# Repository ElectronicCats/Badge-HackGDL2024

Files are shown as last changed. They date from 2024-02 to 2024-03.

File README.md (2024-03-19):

# Badge Hack GDL 2024
Inspirado en la piñata mas famosa del Guadalajara este es el badge electronico de [HackGDL](https://hackgdl.net/)

## Características

- Microcontrolador Puya PY32F002AA15M6TU
- Baterias CR2030
- 4 LEDs SMD

# Firmware
- Para hacer cambios en el firmware revisar el [README](https://github.com/ElectronicCats/Badge-HackGDL2024/tree/main/firmware#readme)

## License
<a>
  
</a>

Diseñado por Electronic Cats para HackGDL

Electronic Cats invests time and resources in providing this open-source design. Please support Electronic Cats and open-source hardware by purchasing products from Electronic Cats!

Hardware released under

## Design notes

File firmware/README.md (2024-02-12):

## Characteristics

* Microcontroller Puya PY32F002A    
  * PY32F002Ax5(20KB Flash/3KB RAM) SPI, USART, I2C, ADC.

## License
<a>
  
</a>

Designed by Electronic Cats for HackGDL

Electronic Cats invests time and resources in providing this open-source design. Please support Electronic Cats and open-source hardware by purchasing products from Electronic Cats!

Hardware released under ...

# PY32F0 SDK reference for Windows

[How to install the SDK for windows](https://github.com/ElectronicCats/puya-projects)

* Puya PY32F0 seriees template project for GNU Arm Embedded Toolchain
* Supported programmers: J-Link
* Supported IDE: VSCode

# File Structure

```
├── Build                       # Build results
├── Docs                        # Datesheets and User Manuals
├── Examples
│   ├── FreeRTOS                # FreeRTOS examples
│   ├── HAL                     # HAL library examples
│   └── LL                      # LL(Low Layer) library examples
├── Libraries
│   ├── BSP                     # SysTick delay and printf for debug
│   ├── BSP_LL                  # SysTick delay and printf for debug
│   ├── CMSIS
│   ├── FreeRTOS                # FreeRTOS library
│   ├── LDScripts               # LD files
│   ├── PY32F0xx_HAL_Driver     # MCU peripheral driver
│   └── PY32F0xx_LL_Driver      # MCU low layer peripheral driver
├── Makefile                    # Make config
├── Misc
│   ├── Flash
│   │   ├── JLinkDevices        # JLink flash loaders
│   │   └── Sources             # Flash algorithm source code
│   ├── Puya.PY32F0xx_DFP.x.pack # DFP pack file for PyOCD
│   └── SVD                     # SVD files
├── README.md
├── rules.mk                    # Pre-defined rules include in Makefile 
└── User                        # User application code
```

# Requirements

* Programmer
  * J-Link: J-Link OB programmer: https://linhkienthuduc.com/jlink-ob-072-mach-nap-cho-arm-cortex-m
* SEGGER J-Link Software and Documentation pack [https://www.segger.com/downloads/jlink/](https://www.segger.com/downloads/jlink/)
* GNU Arm Embedded Toolchain
* Make 

# Try Other Examples

[Forked Repository](https://github.com/IOsetting/py32f0-template)
More examples can be found in *Examples* folder of the forked repository, copy and replace the files under *User* folder of this repository to try different examples.

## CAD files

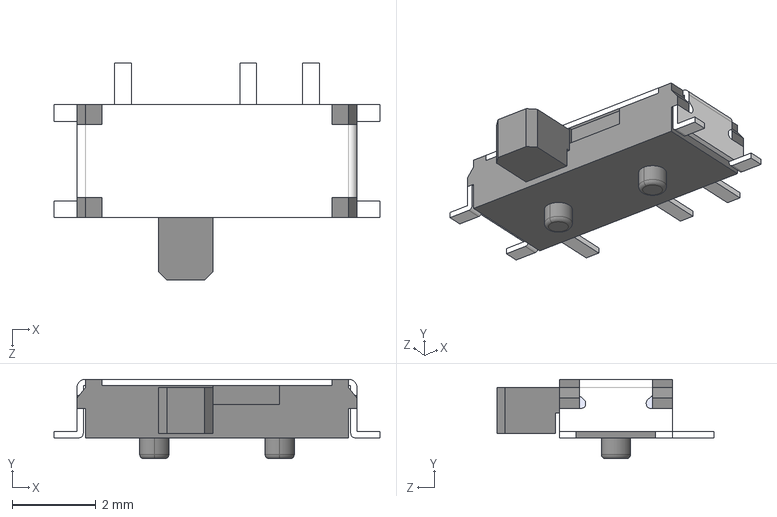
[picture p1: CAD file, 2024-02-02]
hardware/Footprints/3D/MSK12C02.stp
7.80 x 1.90 x 5.20 mm

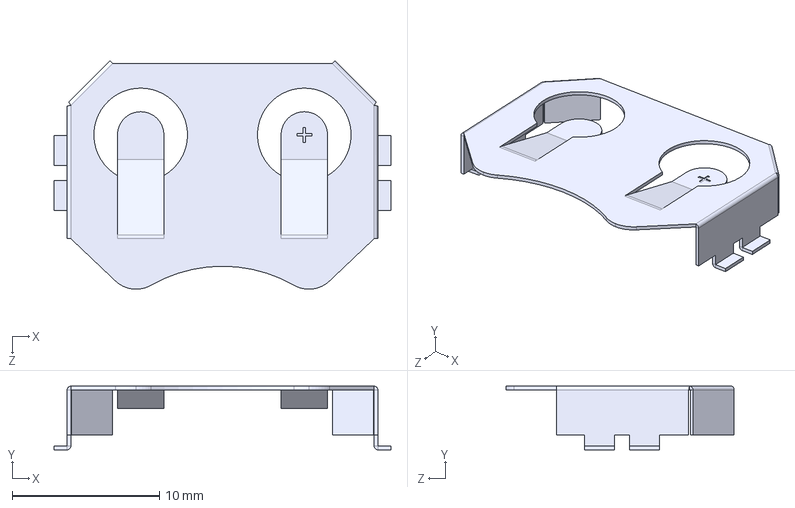
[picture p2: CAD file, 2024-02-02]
hardware/Footprints/3D/BAT-HLD-001--3DModel-STEP-56544.STEP
22.9 x 4.32 x 15.5 mm

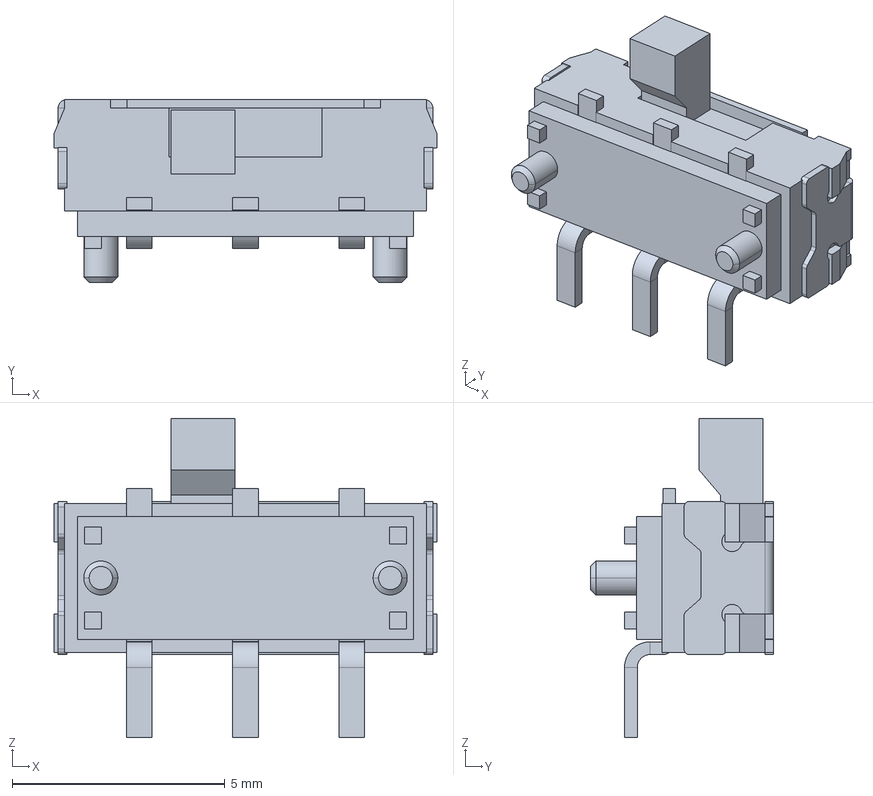
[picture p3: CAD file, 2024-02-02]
hardware/Footprints/3D/JS102011SAQN--3DModel-Eagle-1.STEP
9.00 x 4.30 x 7.50 mm

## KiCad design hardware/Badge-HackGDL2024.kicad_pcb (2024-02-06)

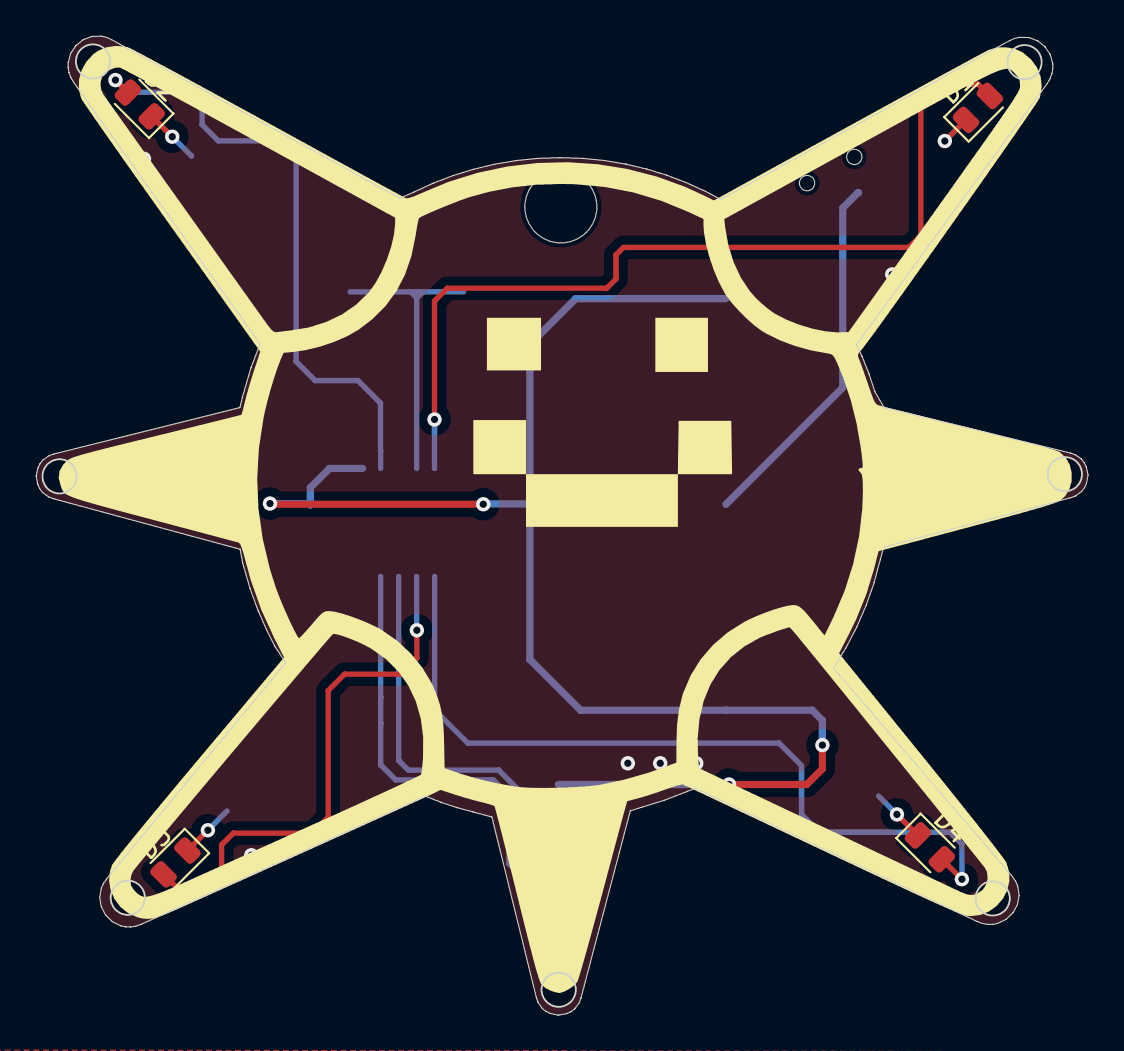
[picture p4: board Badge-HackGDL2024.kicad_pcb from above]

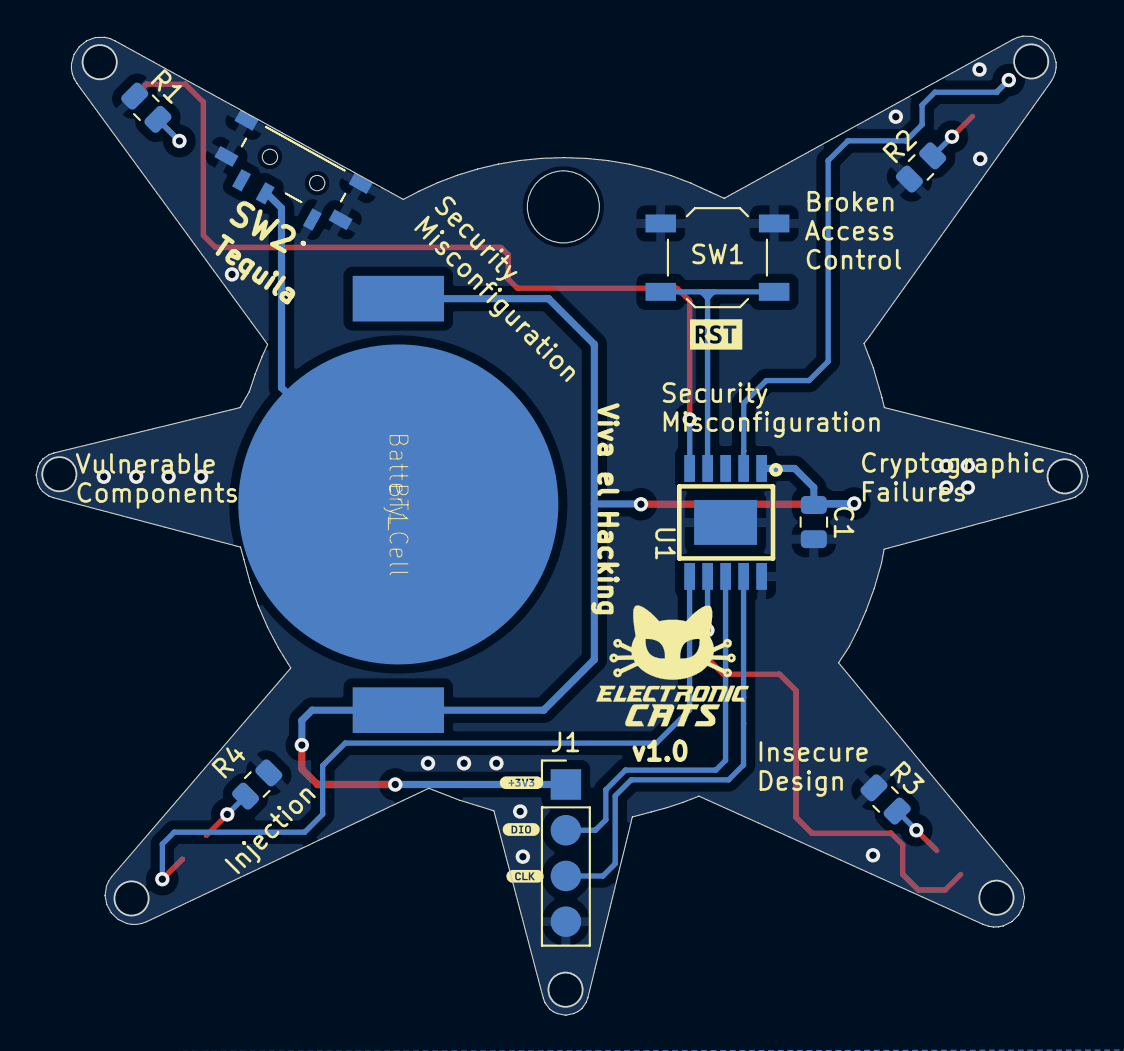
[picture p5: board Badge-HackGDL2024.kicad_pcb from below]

Board: 2 copper layers, 58.4 x 54.4 mm, 18 parts (14 on the bottom side), 14 nets.

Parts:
BT1: Battery_Cell; BAT-HLD-001
C1: 0.1uF; C_0805_2012Metric
D1: Blue; LED_0805_2012Metric
D2: Green; LED_0805_2012Metric
D3: Red; LED_0805_2012Metric
D4: Yellow; LED_0805_2012Metric
J1: SWD; PinHeader_1x04_P2.54mm_Vertical
R1, R2, R3, R4: 330R; R_0805_2012Metric
SW1: SW_RST; SW_SPST_TL3342
SW2: On; MSK12C02
U1: PY32F002AA15M6TU; PY32F002AA15M
kibuzzard-65BC4D69: G***; kibuzzard-65BC4D69
kibuzzard-65BC4D87: G***; kibuzzard-65BC4D87
kibuzzard-65BC4E20: G***; kibuzzard-65BC4E20
kibuzzard-65BD0189: G***; kibuzzard-65BD0189

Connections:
+3.3V: BT1.2 (+), C1.1, J1.1, U1.1 (VCC)
/NRST: SW1.2, U1.4 (PA0/PF2-NRST)
/PA1: D1.2 (A), U1.5 (PA1)
/PA6: D4.2 (A), U1.6 (PA6)
/PA7: D3.2 (A), U1.7 (PA7)
/PF0: D2.2 (A), U1.2 (PF0-OSCIN)
/SWCLK: J1.3, U1.9 (PA14-SWC/PB3)
/SWDIO: J1.2, U1.8 (PA13-SWD)
GND: C1.2, J1.4, R1.1, R2.1, R3.1, R4.1, SW1.1, SW2.1 (A), SW2.4 (C), U1.10 (GND)
unnamed: BT1.1 (-), SW2.2 (B)
unnamed: D1.1 (K), R1.2
unnamed: D2.1 (K), R2.2
unnamed: D3.1 (K), R3.2
unnamed: D4.1 (K), R4.2

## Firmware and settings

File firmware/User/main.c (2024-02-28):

/**
 ******************************************************************************
 * @file    main.c
 * @author  MCU Application Team
 * @brief   Main program body
 ******************************************************************************
 * @attention
 *
 * <h2><center>&copy; Copyright (c) Puya Semiconductor Co.
 * All rights reserved.</center></h2>
 *
 * <h2><center>&copy; Copyright (c) 2016 STMicroelectronics.
 * All rights reserved.</center></h2>
 *
 * This software component is licensed by ST under BSD 3-Clause license,
 * the "License"; You may not use this file except in compliance with the
 * License. You may obtain a copy of the License at:
 *                        opensource.org/licenses/BSD-3-Clause
 *
 * J-Link Connections: https://private-user-images.githubusercontent.com/44976441/277049150-2c44cddc-163c-4924-840f-2b99760bbca3.png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
 * PUYA instructions: https://github.com/ElectronicCats/puya-projects
 *
 ******************************************************************************
 */

/* Includes ------------------------------------------------------------------*/
#include "py32f0xx_bsp_printf.h"
#include <stdint.h>

/* Private define ------------------------------------------------------------*/
/* Private variables ---------------------------------------------------------*/
/* Private user code ---------------------------------------------------------*/
/* Private macro -------------------------------------------------------------*/
/* Private function prototypes -----------------------------------------------*/
static void APP_LedConfig(void);
uint16_t delay1 = 300, interimPeriod = 1000;
uint8_t delay = 150, delay2 = 250, delay3 = 250;
uint8_t times = 0, init = 0, timesSequences = 14, timesSecretCode = 4, sequenceNumber = 1;

uint32_t ports[] = {GPIOF, GPIOA, GPIOA, GPIOA};
uint8_t pins[] = {0x0001, 0x0002, 0x0040, 0x0080};

char message[] = {"HACKGDL"};

void setBits(uint8_t nibble)
{
  uint8_t nibbleAux = nibble;
  for (uint8_t i = 0; i < 4; i++)
  {
    if (nibbleAux & 0x01) // LED ON
    {
      HAL_GPIO_OnPin(ports[i], pins[i]);
    }
    else
    {
      HAL_GPIO_OffPin(ports[i], pins[i]);
    }
    nibbleAux = nibble >> i + 1;
  }
  HAL_Delay(1000);
}

void HEX2NIBBLE()
{
  uint8_t nibble1, nibble2;
  for (uint8_t i = 0; i < sizeof(message) - 1; i++)
  {
    nibble1 = message[i] & 0x0F;
    nibble2 = message[i] >> 4;
    setBits(nibble1);
    setBits(nibble2);
  }
}

// Sequence 1
void circleSequence()
{
  // HAL_Delay(delay);
  HAL_GPIO_OnPin(GPIOF, GPIO_PIN_0); // Start with PF0 ON
  HAL_Delay(delay);
  HAL_GPIO_OffPin(GPIOF, GPIO_PIN_0);
  HAL_GPIO_OnPin(GPIOA, GPIO_PIN_1);
  HAL_Delay(delay);
  HAL_GPIO_OffPin(GPIOA, GPIO_PIN_1);
  HAL_GPIO_OnPin(GPIOA, GPIO_PIN_6);
  HAL_Delay(delay);
  HAL_GPIO_OffPin(GPIOA, GPIO_PIN_6);
  HAL_GPIO_OnPin(GPIOA, GPIO_PIN_7);
  HAL_Delay(delay);
  HAL_GPIO_OffPin(GPIOA, GPIO_PIN_7); // Turn off PA7
  // Return
  HAL_GPIO_OnPin(GPIOF, GPIO_PIN_0); // Start with PF0
  HAL_Delay(delay);
  HAL_GPIO_OffPin(GPIOF, GPIO_PIN_0);
  HAL_GPIO_OnPin(GPIOA, GPIO_PIN_7);
  HAL_Delay(delay);
  HAL_GPIO_OffPin(GPIOA, GPIO_PIN_7);
  HAL_GPIO_OnPin(GPIOA, GPIO_PIN_6);
  HAL_Delay(delay);
  HAL_GPIO_OffPin(GPIOA, GPIO_PIN_6);
  HAL_GPIO_OnPin(GPIOA, GPIO_PIN_1);
  HAL_Delay(delay);
  HAL_GPIO_OffPin(GPIOA, GPIO_PIN_1);
  HAL_Delay(delay);
}

// Sequence 2
void crossSequence()
{
  HAL_GPIO_OnPin(GPIOF, GPIO_PIN_0); // Start with PF0
  HAL_Delay(delay);
  HAL_GPIO_OffPin(GPIOF, GPIO_PIN_0);
  HAL_GPIO_OnPin(GPIOA, GPIO_PIN_6);
  HAL_Delay(delay);
  HAL_GPIO_OffPin(GPIOA, GPIO_PIN_6);
  HAL_GPIO_OnPin(GPIOA, GPIO_PIN_1);
  HAL_Delay(delay);
  HAL_GPIO_OffPin(GPIOA, GPIO_PIN_1);
  HAL_GPIO_OnPin(GPIOA, GPIO_PIN_7);
  HAL_Delay(delay);
  HAL_GPIO_OffPin(GPIOA, GPIO_PIN_7); // Turn off PA7
  HAL_Delay(delay);
}

// Using 2 LEDs at same time
// Seqeuence 3
void crossSequence2()
{
  HAL_GPIO_OnPin(GPIOF, GPIO_PIN_0); // Start with PF0
  HAL_GPIO_OnPin(GPIOA, GPIO_PIN_6); // Start with PA6
  HAL_Delay(delay2);
  HAL_GPIO_OffPin(GPIOF, GPIO_PIN_0);
  HAL_GPIO_OffPin(GPIOA, GPIO_PIN_6);
  HAL_GPIO_OnPin(GPIOA, GPIO_PIN_1);
  HAL_GPIO_OnPin(GPIOA, GPIO_PIN_7);
  HAL_Delay(delay2);
  HAL_GPIO_OffPin(GPIOA, GPIO_PIN_1); // Turn down PA1
  HAL_GPIO_OffPin(GPIOA, GPIO_PIN_7); // Turn down PA7
}
// Seqeuence 4

void continuosCircleSequence()
{
  HAL_GPIO_OnPin(GPIOF, GPIO_PIN_0); // Start with PF0
  HAL_GPIO_OnPin(GPIOA, GPIO_PIN_1); // Start with PA6
  HAL_Delay(delay);
  HAL_GPIO_OffPin(GPIOF, GPIO_PIN_0);
  HAL_GPIO_OnPin(GPIOA, GPIO_PIN_6);
  HAL_Delay(delay);
  HAL_GPIO_OffPin(GPIOA, GPIO_PIN_1);
  HAL_GPIO_OnPin(GPIOA, GPIO_PIN_7);
  HAL_Delay(delay);
  HAL_GPIO_OffPin(GPIOA, GPIO_PIN_6); // Turn down PA1
  HAL_GPIO_OnPin(GPIOF, GPIO_PIN_0);
  HAL_Delay(delay);
  HAL_GPIO_OffPin(GPIOA, GPIO_PIN_7);
}

// Using many LEDs
// Seqeuence 5
void fullCircleSequence()
{
  HAL_GPIO_OnPin(GPIOF, GPIO_PIN_0); // 1
  HAL_Delay(delay2);
  HAL_GPIO_OnPin(GPIOA, GPIO_PIN_1); // 12
  HAL_Delay(delay2);
  HAL_GPIO_OnPin(GPIOA, GPIO_PIN_6); // 123
  HAL_Delay(delay2);
  HAL_GPIO_OnPin(GPIOA, GPIO_PIN_7); // 1234
  HAL_Delay(delay2);
  HAL_GPIO_OffPin(GPIOA, GPIO_PIN_7); // 123
  HAL_Delay(delay2);
  HAL_GPIO_OffPin(GPIOA, GPIO_PIN_6); // 12
  HAL_Delay(delay2);
  HAL_GPIO_OffPin(GPIOA, GPIO_PIN_1); // 1
  HAL_Delay(delay2);
  HAL_GPIO_OffPin(GPIOF, GPIO_PIN_0); // 0
  HAL_Delay(delay2);
  // return sequence
  HAL_GPIO_OnPin(GPIOF, GPIO_PIN_0); // 0
  HAL_Delay(delay2);
  HAL_GPIO_OnPin(GPIOA, GPIO_PIN_7);
  HAL_Delay(delay2);
  HAL_GPIO_OnPin(GPIOA, GPIO_PIN_6);
  HAL_Delay(delay2);
  HAL_GPIO_OnPin(GPIOA, GPIO_PIN_1);
  HAL_Delay(delay2);
  HAL_GPIO_OffPin(GPIOA, GPIO_PIN_1); // return
  HAL_Delay(delay2);
  HAL_GPIO_OffPin(GPIOA, GPIO_PIN_6);
  HAL_Delay(delay2);
  HAL_GPIO_OffPin(GPIOA, GPIO_PIN_7);
  HAL_Delay(delay2);
  HAL_GPIO_OffPin(GPIOF, GPIO_PIN_0); // 0
  HAL_Delay(delay2);
}

// Seqeuence 6
void loadingSequence()
{
  if (init == 0)
  {
    startSequence();
    init = 1;
  }
  HAL_GPIO_OffPin(GPIOA, GPIO_PIN_7);
  HAL_GPIO_OnPin(GPIOA, GPIO_PIN_6); // 123
  HAL_Delay(delay);
  HAL_GPIO_OffPin(GPIOF, GPIO_PIN_0); // Turn off PF0
  HAL_GPIO_OnPin(GPIOA, GPIO_PIN_7);  // 234
  HAL_Delay(delay);
  HAL_GPIO_OffPin(GPIOA, GPIO_PIN_1); // Turn off PA1
  HAL_GPIO_OnPin(GPIOF, GPIO_PIN_0);  // 341
  HAL_Delay(delay);
  HAL_GPIO_OffPin(GPIOA, GPIO_PIN_6); // Turn off PA6
  HAL_GPIO_OnPin(GPIOA, GPIO_PIN_1);  // 412
  HAL_Delay(delay);
  /*
  //return sequence
  HAL_GPIO_TogglePin(GPIOA, GPIO_PIN_7);
  HAL_Delay(delay2);
  HAL_GPIO_TogglePin(GPIOA, GPIO_PIN_6);
  HAL_Delay(delay2);
  HAL_GPIO_TogglePin(GPIOA, GPIO_PIN_1);
  HAL_Delay(delay2);
  HAL_GPIO_TogglePin(GPIOA, GPIO_PIN_1);  //return
  HAL_Delay(delay2);
  HAL_GPIO_TogglePin(GPIOA, GPIO_PIN_6);
  HAL_Delay(delay2);
  HAL_GPIO_TogglePin(GPIOA, GPIO_PIN_7);
  HAL_Delay(delay2);
  */
}

// Seqeuence 7
void blinkSequence()
{
  ledsOn();
  HAL_Delay(delay1);
  ledsOff();
  HAL_Delay(delay1);
}

void startSequence()
{
  HAL_GPIO_OnPin(GPIOF, GPIO_PIN_0); // 1
  HAL_Delay(delay);
  HAL_GPIO_OnPin(GPIOA, GPIO_PIN_1); // 12
  HAL_Delay(delay);
}

// This sequence maybe need to be deleted
void ledsOff()
{
  HAL_GPIO_OffPin(GPIOF, GPIO_PIN_0);
  HAL_GPIO_OffPin(GPIOA, GPIO_PIN_1);
  HAL_GPIO_OffPin(GPIOA, GPIO_PIN_6);
  HAL_GPIO_OffPin(GPIOA, GPIO_PIN_7);
}

void ledsOn()
{
  HAL_GPIO_OnPin(GPIOF, GPIO_PIN_0);
  HAL_GPIO_OnPin(GPIOA, GPIO_PIN_1);
  HAL_GPIO_OnPin(GPIOA, GPIO_PIN_6);
  HAL_GPIO_OnPin(GPIOA, GPIO_PIN_7);
}

void checkTimes()
{
  times += 1;
  if (times == 4)
  {
    sequenceNumber += 1;
    times = 0;
  }
}

void sequences(int sequence)
{
  switch (sequence)
  {
  case 1:
    circleSequence();
    checkTimes();
    break;
  case 2:
    crossSequence();
    checkTimes();
    break;
  case 3:
    crossSequence2();
    checkTimes();
    break;
  case 4:
    continuosCircleSequence();
    checkTimes();
    break;
  case 5:
    fullCircleSequence();
    checkTimes();
    break;
  case 6:
    loadingSequence();
    checkTimes();
    break;
  case 7:
    blinkSequence();
    blinkSequence();
    blinkSequence();
    checkTimes();
    break;
  default:
    ledsOn();
    sequenceNumber = 1;
    HAL_Delay(1000);
    break;
  }
}

int main(void)
{
  HAL_Init();

  APP_LedConfig();

  BSP_USART_Config();
  
  while (1)
  {
    for (uint8_t c = 1; c < 7; c++)
    {
      sequences(c);
    }

    for (uint8_t c2 = 0; c2 < timesSecretCode; c2++)
    {
      sequences(7); // Blink Sequence 3 times
      ledsOff();
      HAL_Delay(interimPeriod);
      HEX2NIBBLE();
      ledsOff();
      HAL_Delay(interimPeriod);
    }
  }
}

static void APP_LedConfig(void)
{
  GPIO_InitTypeDef GPIO_InitStruct;

  __HAL_RCC_GPIOA_CLK_ENABLE();

  GPIO_InitStruct.Pin = GPIO_PIN_1;
  GPIO_InitStruct.Mode = GPIO_MODE_OUTPUT_PP;
  GPIO_InitStruct.Pull = GPIO_PULLUP;
  GPIO_InitStruct.Speed = GPIO_SPEED_FREQ_HIGH;
  HAL_GPIO_Init(GPIOA, &GPIO_InitStruct);

  __HAL_RCC_GPIOA_CLK_ENABLE();

  GPIO_InitStruct.Pin = GPIO_PIN_6;
  GPIO_InitStruct.Mode = GPIO_MODE_OUTPUT_PP;
  GPIO_InitStruct.Pull = GPIO_PULLUP;
  GPIO_InitStruct.Speed = GPIO_SPEED_FREQ_HIGH;
  HAL_GPIO_Init(GPIOA, &GPIO_InitStruct);

  __HAL_RCC_GPIOA_CLK_ENABLE();

  GPIO_InitStruct.Pin = GPIO_PIN_7;
  GPIO_InitStruct.Mode = GPIO_MODE_OUTPUT_PP;
  GPIO_InitStruct.Pull = GPIO_PULLUP;
  GPIO_InitStruct.Speed = GPIO_SPEED_FREQ_HIGH;

  HAL_GPIO_Init(GPIOA, &GPIO_InitStruct);

  __HAL_RCC_GPIOF_CLK_ENABLE();

  GPIO_InitStruct.Pin = GPIO_PIN_0;
  GPIO_InitStruct.Mode = GPIO_MODE_OUTPUT_PP;
  GPIO_InitStruct.Pull = GPIO_PULLUP;
  GPIO_InitStruct.Speed = GPIO_SPEED_FREQ_HIGH;

  HAL_GPIO_Init(GPIOF, &GPIO_InitStruct);
}

void APP_ErrorHandler(void)
{
  while (1)
    ;
}

#ifdef USE_FULL_ASSERT

void assert_failed(uint8_t *file, uint32_t line)
{
  while (1)
  {
  }
}
#endif /* USE_FULL_ASSERT */

/************************ (C) COPYRIGHT Puya *****END OF FILE******************/

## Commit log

2024-02-02 Schematic and PCB started
    [Badge-HackGDL2023.kicad_pcb, Badge-HackGDL2023.kicad_sch]
2024-02-02 add first edge cuts
    [Badge-HackGDL2023.kicad_pcb]
2024-02-02 Update routing
    [BAT-HLD-001--3DModel-STEP-56544.STEP, Badge-HackGDL2023.kicad_pcb, JS102011SAQN--3DModel-Eagle-1.STEP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]
2024-02-02 Update BOM
    [Badge-HackGDL2023.kicad_sch]
2024-02-02 update labels
    [Badge-HackGDL2023.kicad_pcb]
2024-02-12 LED's Firmware with 7 different sequences
2024-02-28 fix: infinite loop added
    [main.c]
2024-03-19 fix(hw): rename files
    [Badge-HackGDL2024.kicad_pcb, Badge-HackGDL2024.kicad_sch]
